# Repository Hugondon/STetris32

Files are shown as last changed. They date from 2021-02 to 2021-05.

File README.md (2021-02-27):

# STetris32
My version of the famous game "Tetris" using a system based on the Blue Pill dev board.
## Information
The sole purpose of this project is to recreate the game mechanics and introduce some other different features regarding in-game audio :). 
## Block Diagram
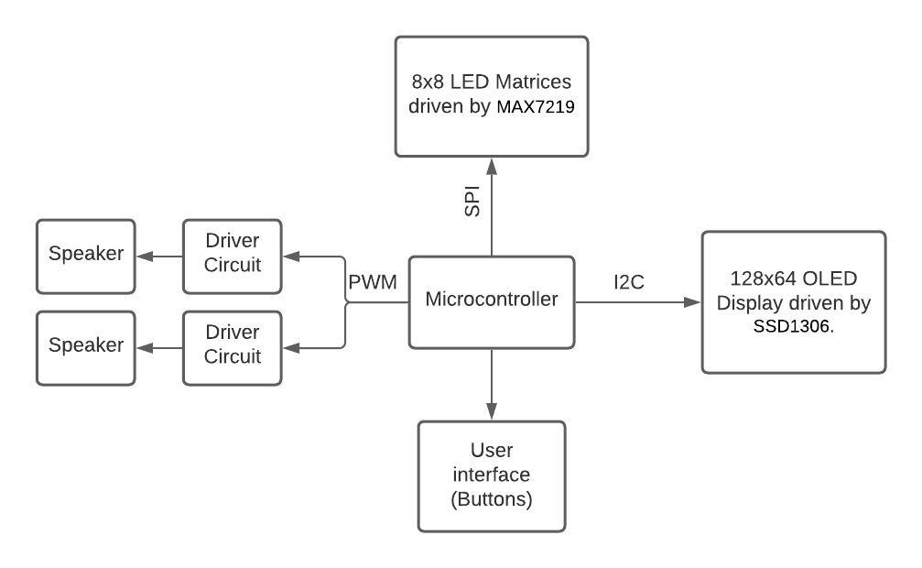
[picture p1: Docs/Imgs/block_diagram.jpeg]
block_diagram

The system can be summarized in three big modules:
1. Game Display Module.
    - SPI communication with MAX7219 to control two 8x8 LED matrices.
    - I2C communication with SSD1306 OLED Driver connected to 128x64 dot display to show the player's score and the current song being played.
2. Sound Module.
    - PWM + NPN BJT circuit driven 4 ohm speakers.
3. User Interface Module.
    - 6 buttons with different functionalities (up/down/left/right/center/reset).
## Schematic
The connections the user must make are the following:
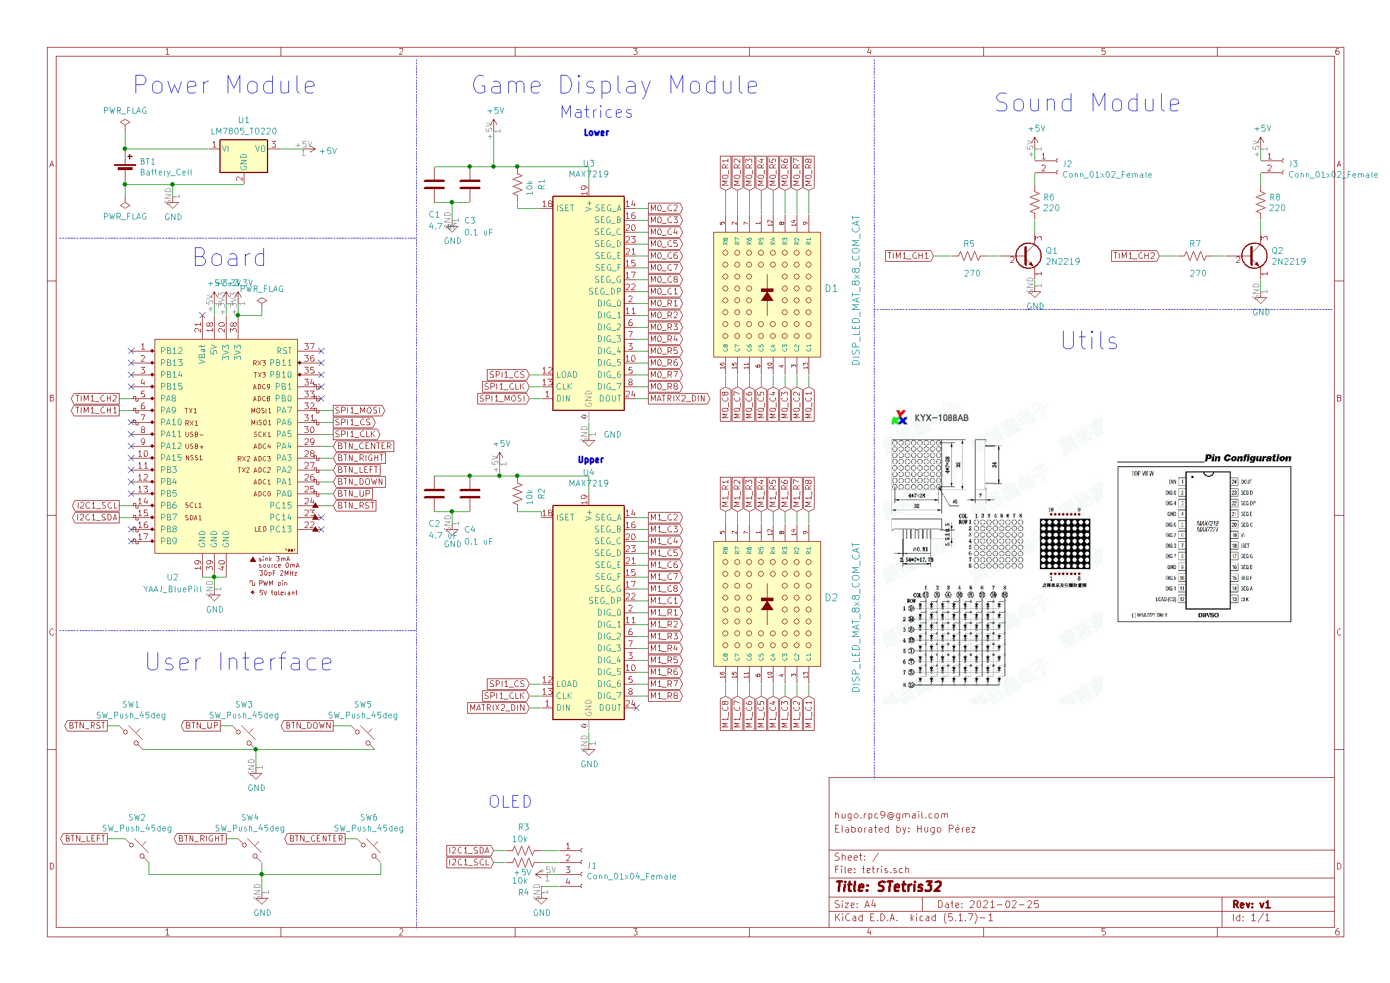
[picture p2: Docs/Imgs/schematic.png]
schematic

## Video

Pending upload.

## Useful Information
- [OLED Display](https://controllerstech.com/oled-display-using-i2c-stm32/)
- [Matrices](https://acoptex.com/project/160/basics-project-032a-8x8-dot-led-matrix-64-led-digital-display-common-anode-and-common-cathode-at-lex-c/)

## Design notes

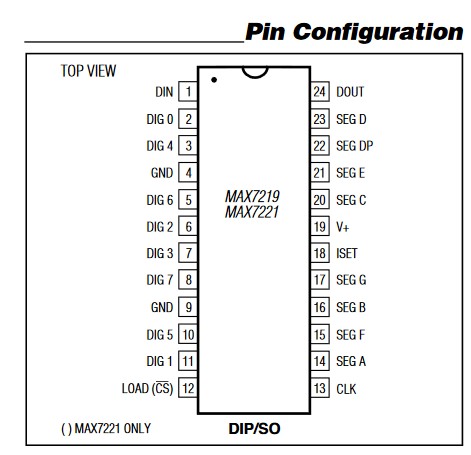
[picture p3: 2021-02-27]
Docs/Imgs/max7219_pinout.jpg

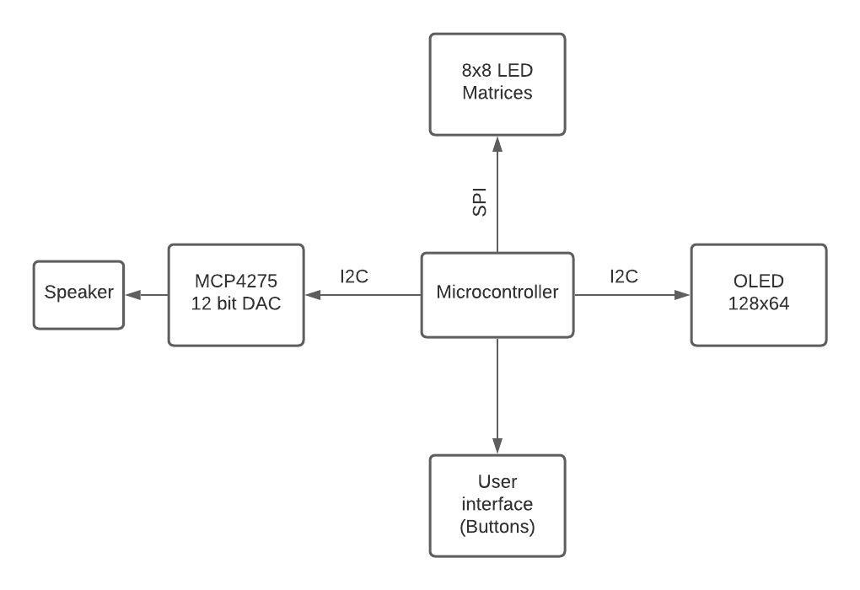
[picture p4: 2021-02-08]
Docs/Imgs/STetris32.jpeg

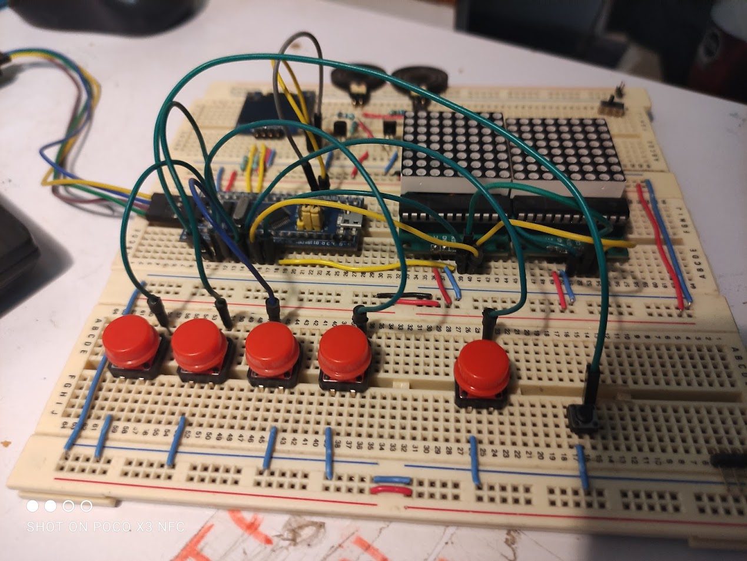
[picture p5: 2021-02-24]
Docs/Imgs/protoboard_project.jpg

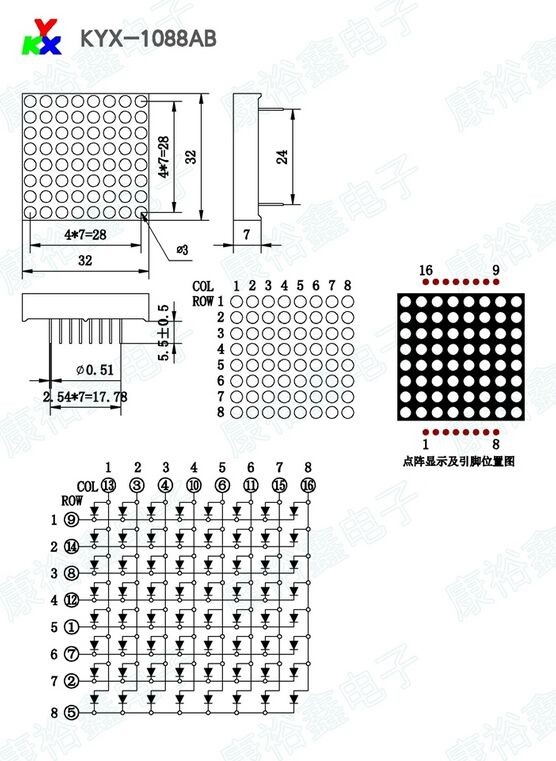
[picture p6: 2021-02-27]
Docs/Imgs/matrices_example.jpg

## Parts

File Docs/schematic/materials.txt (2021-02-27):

// Board
1. 1 x Bluepill					(2 x Conn_01x20_Female)	X

// User Interface
2. 6 x push-buttons				(SW_PUSH_12mm)		?

// Game Display Module
-- Matrices --
3. 2 x MAX7219					(DIP-24)		X
4. 4 x Conn_01x08_Female 			(matrices)		X
5. 2 x 10 uF Electrolytic Capacitor 		(4.7 uF 0603)		?
6. 2 x 0.1 uF Ceramic Capacitor			(0603)			X
7. 2 x 10K Resistance 				(0603)			X
-- OLED --
8. 2 x 10K Resistance				(0603)			X
9. 1 x Conn_01x04_Female						X

// Sound Module
9.  2 x BJT 2N2222A Transistors 		(TO - 92)		X
10. 2 x 330 Resistance (1/4 W)			(270 0603)		X
11. 2 x 68 Resistance (1/4 W)			(220 0603)		X
12. 2 x Conn_01x02_Female 			(Speakers)		X

// Power Module
12. 9V Battery					(BatteryHolder_MPD_BA9VPC_1xPP3)     ? 
13. 7805 regulator				(TO - 220)		X

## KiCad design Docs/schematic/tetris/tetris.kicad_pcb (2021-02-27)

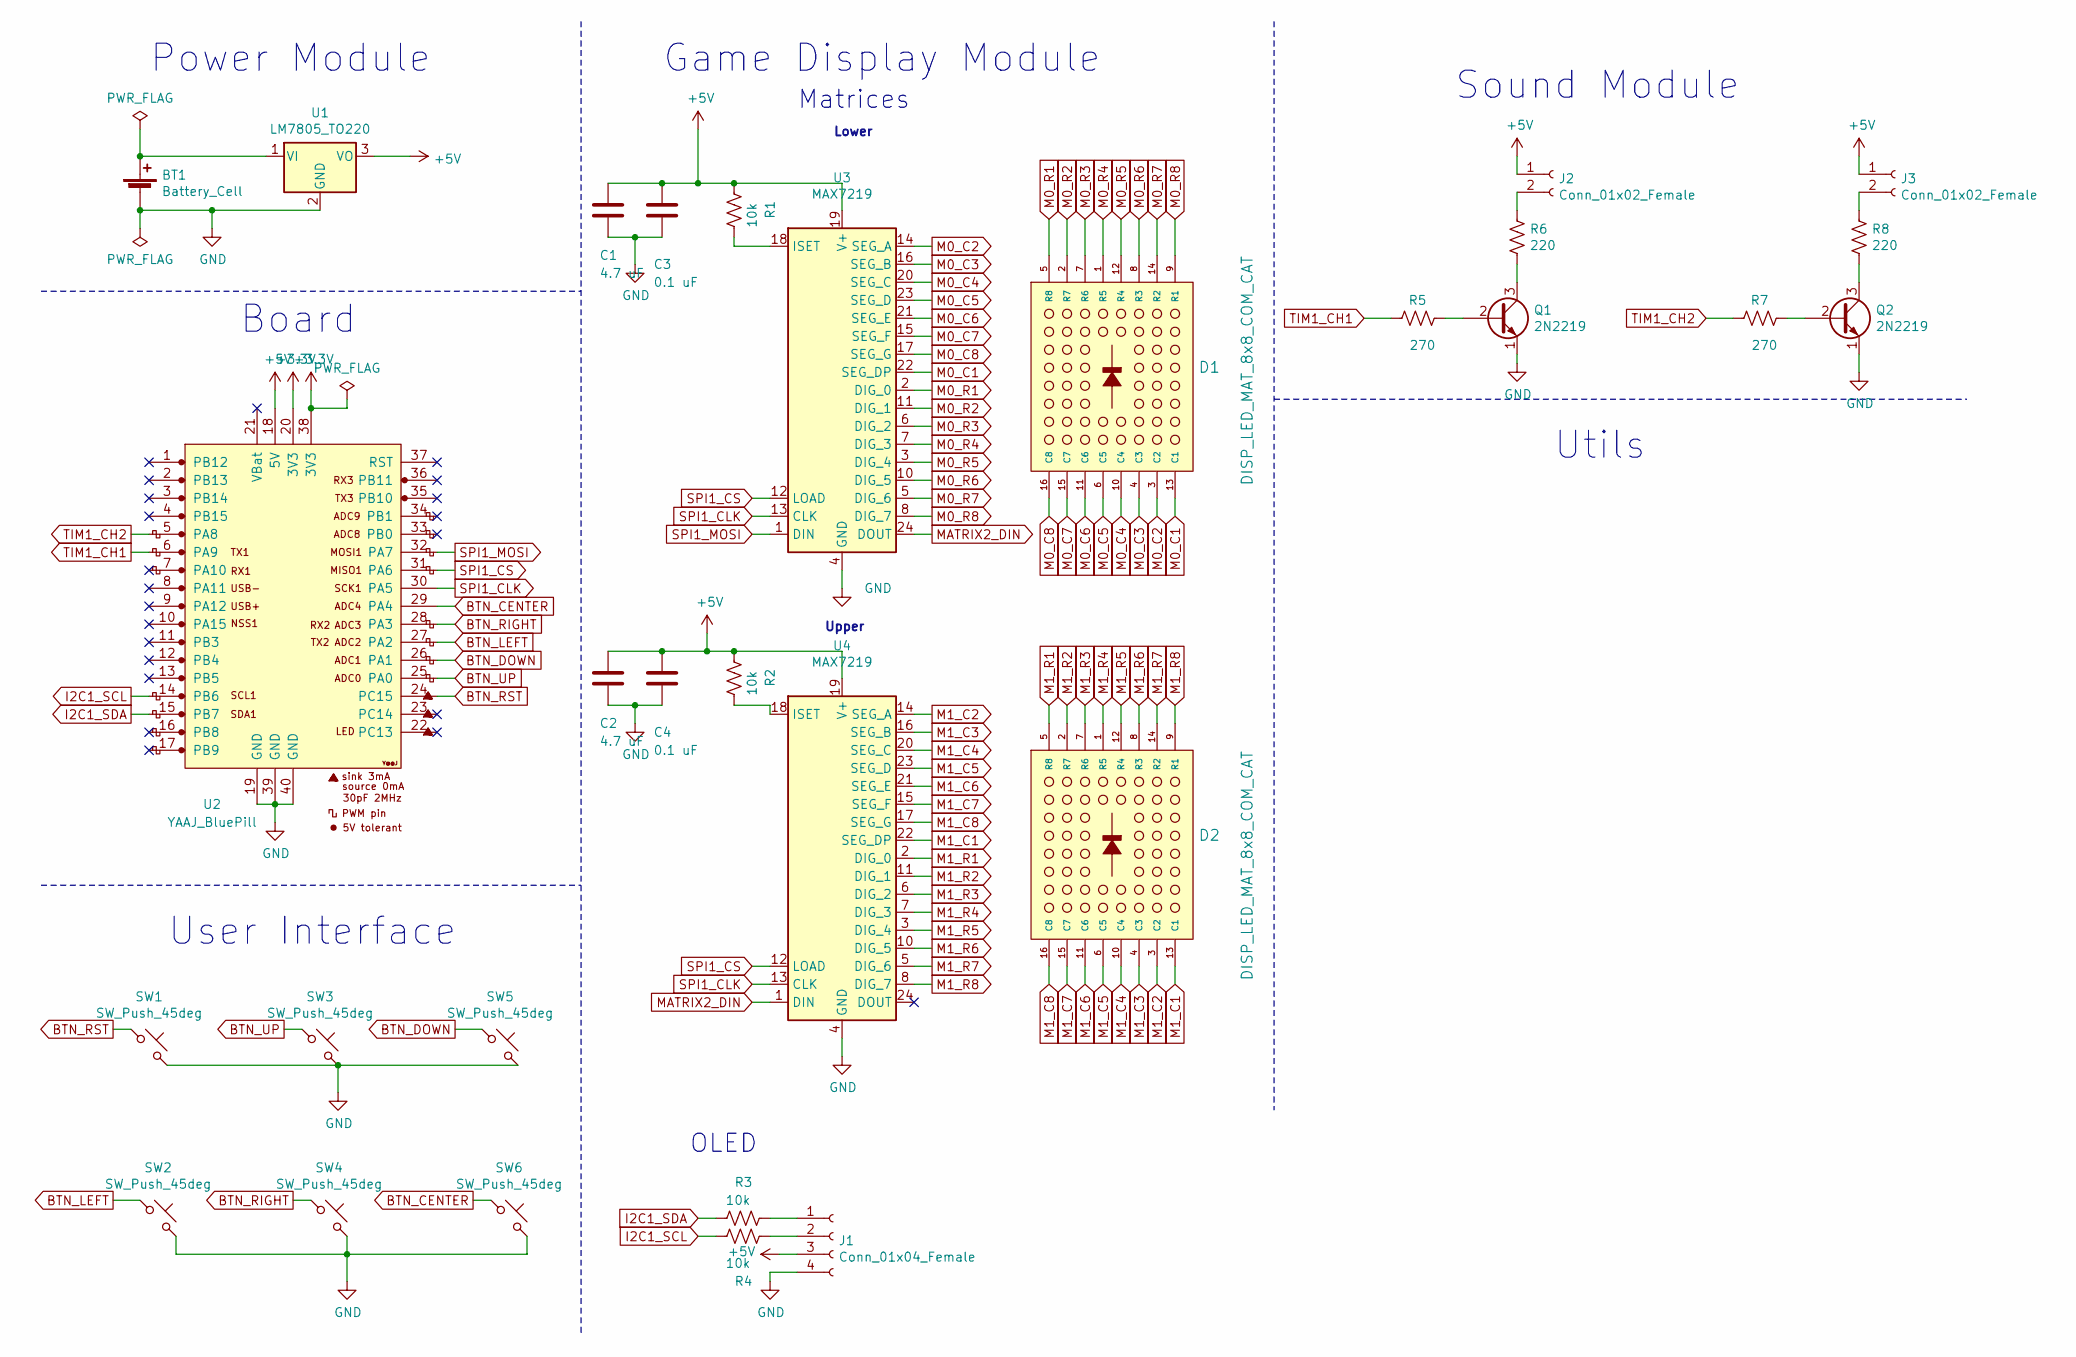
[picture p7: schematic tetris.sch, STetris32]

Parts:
BT1: Battery_Cell; BatteryHolder_MPD_BA9VPC_1xPP3
C1, C2: 4.7 uF; C_0603_1608Metric
C3, C4: 0.1 uF; C_0603_1608Metric
D1, D2: DISP_LED_MAT_8x8_COM_CAT; LED_8x8_3MM_32x32MM
J1: Conn_01x04_Female; PinHeader_1x04_P2.54mm_Vertical
J2, J3: Conn_01x02_Female; PinHeader_1x02_P2.54mm_Vertical
Q1, Q2: 2N2219; TO-92
R1, R2, R3, R4: 10k; R_0603_1608Metric
R5, R7: 270; R_0603_1608Metric
R6, R8: 220; R_0603_1608Metric
SW1, SW2, SW3, SW4, SW5, SW6: SW_Push_45deg; SW_PUSH-12mm
U1: LM7805_TO220; TO-220-3_Vertical
U2: YAAJ_BluePill; YAAJ_BluePill_1
U3, U4: MAX7219; DIP-24_W7.62mm

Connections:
+3V3: U2.20 (3V3), U2.38 (3V3)
+5V: C1.1, C2.1, C3.1, C4.1, J1.3, J2.1, J3.1, R1.1, R2.1, U1.3 (VO), U2.18 (5V), U3.19 (V+), U4.19 (V+)
BTN_CENTER: SW6.1, U2.29 (PA4)
BTN_DOWN: SW5.1, U2.26 (PA1)
BTN_LEFT: SW2.1, U2.27 (PA2)
BTN_RIGHT: SW4.1, U2.28 (PA3)
BTN_RST: SW1.1, U2.24 (PC15)
BTN_UP: SW3.1, U2.25 (PA0)
GND: BT1.2 (-), C1.2, C2.2, C3.2, C4.2, J1.4, Q1.1 (E), Q2.1 (E), SW1.2, SW2.2, SW3.2, SW4.2, SW5.2, SW6.2, U1.2 (GND), U2.19 (GND), U2.39 (GND), U2.40 (GND), U3.4 (GND), U3.9 (GND), U4.4 (GND), U4.9 (GND)
I2C1_SCL: R4.2, U2.14 (PB6)
I2C1_SDA: R3.2, U2.15 (PB7)
M0_C1: D1.13 (C1), U3.22 (SEG_DP)
M0_C2: D1.3 (C2), U3.14 (SEG_A)
M0_C3: D1.4 (C3), U3.16 (SEG_B)
M0_C4: D1.10 (C4), U3.20 (SEG_C)
M0_C5: D1.6 (C5), U3.23 (SEG_D)
M0_C6: D1.11 (C6), U3.21 (SEG_E)
M0_C7: D1.15 (C7), U3.15 (SEG_F)
M0_C8: D1.16 (C8), U3.17 (SEG_G)
M0_R1: D1.5 (R8), U3.2 (DIG_0)
M0_R2: D1.2 (R7), U3.11 (DIG_1)
M0_R3: D1.7 (R6), U3.6 (DIG_2)
M0_R4: D1.1 (R5), U3.7 (DIG_3)
M0_R5: D1.12 (R4), U3.3 (DIG_4)
M0_R6: D1.8 (R3), U3.10 (DIG_5)
M0_R7: D1.14 (R2), U3.5 (DIG_6)
M0_R8: D1.9 (R1), U3.8 (DIG_7)
M1_C1: D2.13 (C1), U4.22 (SEG_DP)
M1_C2: D2.3 (C2), U4.14 (SEG_A)
M1_C3: D2.4 (C3), U4.16 (SEG_B)
M1_C4: D2.10 (C4), U4.20 (SEG_C)
M1_C5: D2.6 (C5), U4.23 (SEG_D)
M1_C6: D2.11 (C6), U4.21 (SEG_E)
M1_C7: D2.15 (C7), U4.15 (SEG_F)
M1_C8: D2.16 (C8), U4.17 (SEG_G)
M1_R1: D2.5 (R8), U4.2 (DIG_0)
M1_R2: D2.2 (R7), U4.11 (DIG_1)
M1_R3: D2.7 (R6), U4.6 (DIG_2)
M1_R4: D2.1 (R5), U4.7 (DIG_3)
M1_R5: D2.12 (R4), U4.3 (DIG_4)
M1_R6: D2.8 (R3), U4.10 (DIG_5)
M1_R7: D2.14 (R2), U4.5 (DIG_6)
M1_R8: D2.9 (R1), U4.8 (DIG_7)
MATRIX2_DIN: U3.24 (DOUT), U4.1 (DIN)
unnamed: BT1.1 (+), U1.1 (VI)
unnamed: J1.1, R3.1
unnamed: J1.2, R4.1
unnamed: J2.2, R6.1
unnamed: J3.2, R8.1
unnamed: Q1.2 (B), R5.2
unnamed: Q1.3 (C), R6.2
unnamed: Q2.2 (B), R7.2
unnamed: Q2.3 (C), R8.2
unnamed: R1.2, U3.18 (ISET)
unnamed: R2.2, U4.18 (ISET)
SPI1_CLK: U2.30 (PA5), U3.13 (CLK), U4.13 (CLK)
SPI1_CS: U2.31 (PA6), U3.12 (LOAD), U4.12 (LOAD)
SPI1_MOSI: U2.32 (PA7), U3.1 (DIN)
TIM1_CH1: R5.1, U2.6 (PA9)
TIM1_CH2: R7.1, U2.5 (PA8)

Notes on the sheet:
Power Module
Board
User Interface
Game Display Module
Sound Module
Matrices
OLED
Utils
Lower
Upper

Board: 2 copper layers, 30 parts (0 on the bottom side), 60 nets, no tracks yet.

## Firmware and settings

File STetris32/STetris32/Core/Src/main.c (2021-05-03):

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
/* Includes ------------------------------------------------------------------*/
#include "main.h"

/* USER CODE BEGIN Includes */
#include <stdio.h>
#include <stdbool.h>
#include "ssd1306.h"
#include "fonts.h"
#include "test.h"
#include "sound.h"
#include "matrix.h"
/* USER CODE END Includes */

I2C_HandleTypeDef hi2c1;

SPI_HandleTypeDef hspi1;

TIM_HandleTypeDef htim1;
TIM_HandleTypeDef htim2;
TIM_HandleTypeDef htim3;

/* USER CODE BEGIN PV */

/*  Matrices Module */
extern row_t test_array[][8];
extern row_t figures_array[][8];
extern row_t matrix_buffer[8][8];

/*  Display Module */
uint32_t high_score = 9990;
char high_score_user[15];
char high_score_str[20];

/*  Audio Module */
extern uint16_t psc_array[];
extern uint16_t arr_array[];
extern uint8_t array_index;

extern const uint8_t melody[];
extern const size_t sizeof_melody;
extern uint8_t noteDurations[];

// General Purpose
bool center_flag = false;

/* USER CODE END PV */

void SystemClock_Config(void);
static void MX_GPIO_Init(void);
static void MX_SPI1_Init(void);
static void MX_I2C1_Init(void);
static void MX_TIM2_Init(void);
static void MX_TIM1_Init(void);
static void MX_TIM3_Init(void);
/* USER CODE BEGIN PFP */

// Interface
void update_player_score(int points);

/* USER CODE END PFP */

/**
  * @brief  The application entry point.
  * @retval int
  */
int main(void)
{
  /* MCU Configuration--------------------------------------------------------*/

  /* Reset of all peripherals, Initializes the Flash interface and the Systick. */
  HAL_Init();

  /* Configure the system clock */
  SystemClock_Config();

  /* Initialize all configured peripherals */
  MX_GPIO_Init();
  MX_SPI1_Init();
  MX_I2C1_Init();
  MX_TIM2_Init();
  MX_TIM1_Init();
  MX_TIM3_Init();
  /* USER CODE BEGIN 2 */

  // Matrices
  max_init();
  max_init();

  for(int i = 1 ; i < 9; i++){
	matrix_buffer[Upper][i-1] = figures_array[Upper][i-1];
	matrix_buffer[Lower][i-1] = figures_array[Lower][i-1];
	max_transfer_data(i, matrix_buffer[Upper][i-1], matrix_buffer[Lower][i-1]);
  }

  // LCD
  SSD1306_Init();
  SSD1306_Fill(0);

  SSD1306_GotoXY(25, 0);
  SSD1306_Puts("Welcome!", &Font_11x18, 1);
  SSD1306_GotoXY(30, 20);
  SSD1306_Puts("High Score", &Font_7x10, 1);

  SSD1306_GotoXY(0, 35);
  strcpy(high_score_user, "Hugo Perez");
  // snprintf(high_score_user, strlen("Hugo Perez") + 1, "Hugo Perez");
  sprintf(high_score_str, "%s - %05lu", high_score_user, high_score);
  SSD1306_Puts(high_score_str, &Font_7x10, 1);

  SSD1306_DrawLine(0, 32, 140, 32, 1);
  SSD1306_DrawLine(0, 45, 140, 45, 1);

  SSD1306_GotoXY(20, 50);
  SSD1306_Puts("Press Center", &Font_7x10, 1);

  SSD1306_UpdateScreen();

  int i = 0;
  /* USER CODE END 2 */

  /* Infinite loop */
  /* USER CODE BEGIN WHILE */
  while (1)
  {
    /* USER CODE END WHILE */

    /* USER CODE BEGIN 3 */
	  custom_tone(TIM_CHANNEL_1, melody[i], noteDurations[i]);
	  i = (i < sizeof_melody/sizeof(int) ? i + 1 : 0);
  }
  /* USER CODE END 3 */
}

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
/* USER CODE BEGIN 4 */
void max_transfer_command(uint8_t address, uint8_t data){
	HAL_GPIO_WritePin(SPI1_CS_GPIO_Port, SPI1_CS_Pin, GPIO_PIN_RESET);
	HAL_SPI_Transmit(&hspi1, &address, 1, 100);
	HAL_SPI_Transmit(&hspi1, &data, 1, 100);
	HAL_GPIO_WritePin(SPI1_CS_GPIO_Port, SPI1_CS_Pin, GPIO_PIN_SET);
}
void max_transfer_data(uint8_t address, uint8_t data, uint8_t data_2){
	HAL_GPIO_WritePin(SPI1_CS_GPIO_Port, SPI1_CS_Pin, GPIO_PIN_RESET);
	HAL_SPI_Transmit(&hspi1, &address, 1, 100);
	HAL_SPI_Transmit(&hspi1, &data, 1, 100);							// Upper
	HAL_SPI_Transmit(&hspi1, &address, 1, 100);
	HAL_SPI_Transmit(&hspi1, &data_2, 1, 100);							// Lower
	HAL_GPIO_WritePin(SPI1_CS_GPIO_Port, SPI1_CS_Pin, GPIO_PIN_SET);
}

void shift_matrix_content(uint8_t direction){
	row_t tmp_row;
	switch(direction){
	case up:
		  HAL_GPIO_TogglePin(LED_BUILTIN_GPIO_Port, LED_BUILTIN_Pin);
		  // Pending rotations
			for(int i = 1 ; i < 9; i++){
				matrix_buffer[Upper][i-1] = test_array[Upper][i-1];
				matrix_buffer[Lower][i-1] = test_array[Lower][i-1];
				max_transfer_data(i, matrix_buffer[Upper][i-1], matrix_buffer[Lower][i-1]);
			}
		break;
	case down:
		HAL_GPIO_TogglePin(LED_BUILTIN_GPIO_Port, LED_BUILTIN_Pin);

		tmp_row = matrix_buffer[Upper][0];

		for(int i = 1 ; i < 8; i++){
			matrix_buffer[Upper][i-1] = matrix_buffer[Upper][i];
			matrix_buffer[Lower][i-1] = matrix_buffer[Lower][i];
			max_transfer_data(i, matrix_buffer[Upper][i-1], matrix_buffer[Lower][i-1]);
		}
		matrix_buffer[Upper][7] = 0b00000000;
		matrix_buffer[Lower][7] = tmp_row;
		max_transfer_data(8, matrix_buffer[Upper][7], matrix_buffer[Lower][7]);
		break;
	case left:
		  HAL_GPIO_TogglePin(LED_BUILTIN_GPIO_Port, LED_BUILTIN_Pin);
		  for(int i = 1; i < 9; i++){
			matrix_buffer[Upper][i-1] = matrix_buffer[Upper][i-1] >> 1;
			matrix_buffer[Lower][i-1] = matrix_buffer[Lower][i-1] >> 1;
			max_transfer_data(i, matrix_buffer[Upper][i-1], matrix_buffer[Lower][i-1]);
		  }

		break;
	case right:
		  HAL_GPIO_TogglePin(LED_BUILTIN_GPIO_Port, LED_BUILTIN_Pin);
		  for(int i = 1; i < 9; i++){
			matrix_buffer[Upper][i-1] = matrix_buffer[Upper][i-1] << 1;
			matrix_buffer[Lower][i-1] = matrix_buffer[Lower][i-1] << 1;
			max_transfer_data(i, matrix_buffer[Upper][i-1], matrix_buffer[Lower][i-1]);
		  }
		break;
	}

}
void update_player_score(int points){
	high_score += points;
	SSD1306_GotoXY(0, 35);
	sprintf(high_score_str, "%s - %05lu", high_score_user, high_score);
	SSD1306_Puts(high_score_str, &Font_7x10, 1);
	SSD1306_UpdateScreen();
}

void custom_tone(uint32_t channel, uint8_t tone, uint8_t duration){
	  htim1.Init.Prescaler = psc_array[tone]-1;
	  htim1.Init.Period = arr_array[tone]-1;
	  HAL_TIM_Base_Init(&htim1);
	  HAL_TIM_PWM_Start(&htim1, TIM_CHANNEL_1);
	  HAL_TIM_PWM_Start(&htim1, TIM_CHANNEL_2);

	  htim3.Init.Prescaler = (1000*1.3)-1;
	  htim3.Init.Period = (1000/duration)-1;
	  HAL_Delay(200);
	  HAL_TIM_Base_Start_IT(&htim3);
}


void HAL_GPIO_EXTI_Callback(uint16_t GPIO_Pin){
	if(GPIO_Pin == BTN_UP_Pin) HAL_TIM_Base_Start_IT(&htim2);
	if(GPIO_Pin == BTN_DOWN_Pin) HAL_TIM_Base_Start_IT(&htim2);
	if(GPIO_Pin == BTN_LEFT_Pin) HAL_TIM_Base_Start_IT(&htim2);
	if(GPIO_Pin == BTN_RIGHT_Pin) HAL_TIM_Base_Start_IT(&htim2);
	if(GPIO_Pin == BTN_CENTER_Pin) HAL_TIM_Base_Start_IT(&htim2);
	if(GPIO_Pin == BTN_RST_Pin) HAL_TIM_Base_Start_IT(&htim2);


}
void HAL_TIM_PeriodElapsedCallback(TIM_HandleTypeDef *htim){
  /* Prevent unused argument(s) compilation warning */
  if(htim == &htim2){

	  if(!HAL_GPIO_ReadPin(BTN_UP_GPIO_Port, BTN_UP_Pin)){
		  update_player_score(1);
		  shift_matrix_content(up);
		  HAL_TIM_Base_Stop(&htim2);
	  }
	  if(!HAL_GPIO_ReadPin(BTN_DOWN_GPIO_Port, BTN_DOWN_Pin)){
		  update_player_score(-1);
		  shift_matrix_content(down);
		  HAL_TIM_Base_Stop(&htim2);
	  }
	  if(!HAL_GPIO_ReadPin(BTN_LEFT_GPIO_Port, BTN_LEFT_Pin)){
		  shift_matrix_content(left);
		  HAL_TIM_Base_Stop(&htim2);
	  }
	  if(!HAL_GPIO_ReadPin(BTN_RIGHT_GPIO_Port, BTN_RIGHT_Pin)){
		  shift_matrix_content(right);
		  HAL_TIM_Base_Stop(&htim2);
	  }
	  if(!HAL_GPIO_ReadPin(BTN_CENTER_GPIO_Port, BTN_CENTER_Pin)){
		  HAL_GPIO_TogglePin(LED_BUILTIN_GPIO_Port, LED_BUILTIN_Pin);
		  center_flag = true;

		  HAL_TIM_Base_Stop(&htim2);
	  }
	  if(!HAL_GPIO_ReadPin(BTN_RST_GPIO_Port, BTN_RST_Pin)){
		  HAL_GPIO_TogglePin(LED_BUILTIN_GPIO_Port, LED_BUILTIN_Pin);
		  HAL_TIM_Base_Stop(&htim2);
	  }

  }
  if(htim == &htim3){
	  	  HAL_TIM_Base_Stop(&htim3);
  }
}
/* USER CODE END 4 */
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


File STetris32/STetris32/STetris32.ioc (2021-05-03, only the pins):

Mcu.UserName=STM32F103C8Tx
PA0-WKUP.GPIO_Label=BTN_UP
PA0-WKUP.Signal=GPXTI0
PA1.GPIO_Label=BTN_DOWN
PA1.Signal=GPXTI1
PA13.Signal=SYS_JTMS-SWDIO
PA14.Signal=SYS_JTCK-SWCLK
PA2.GPIO_Label=BTN_LEFT
PA2.Signal=GPXTI2
PA3.GPIO_Label=BTN_RIGHT
PA3.Signal=GPXTI3
PA4.GPIO_Label=BTN_CENTER
PA4.Signal=GPXTI4
PA5.Signal=SPI1_SCK
PA6.GPIO_Label=SPI1_CS
PA6.Signal=GPIO_Output
PA7.Signal=SPI1_MOSI
PA8.Signal=S_TIM1_CH1
PA9.Signal=S_TIM1_CH2
PB6.Signal=I2C1_SCL
PB7.Signal=I2C1_SDA
PC13-TAMPER-RTC.GPIO_Label=LED_BUILTIN
PC13-TAMPER-RTC.Signal=GPIO_Output
PC15-OSC32_OUT.GPIO_Label=BTN_RST
PC15-OSC32_OUT.Signal=GPXTI15
PD0-OSC_IN.Signal=RCC_OSC_IN
PD1-OSC_OUT.Signal=RCC_OSC_OUT

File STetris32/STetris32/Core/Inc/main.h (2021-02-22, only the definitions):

#define LED_BUILTIN_Pin GPIO_PIN_13
#define LED_BUILTIN_GPIO_Port GPIOC
#define BTN_RST_Pin GPIO_PIN_15
#define BTN_RST_GPIO_Port GPIOC
#define BTN_RST_EXTI_IRQn EXTI15_10_IRQn
#define BTN_UP_Pin GPIO_PIN_0
#define BTN_UP_GPIO_Port GPIOA
#define BTN_UP_EXTI_IRQn EXTI0_IRQn
#define BTN_DOWN_Pin GPIO_PIN_1
#define BTN_DOWN_GPIO_Port GPIOA
#define BTN_DOWN_EXTI_IRQn EXTI1_IRQn
#define BTN_LEFT_Pin GPIO_PIN_2
#define BTN_LEFT_GPIO_Port GPIOA
#define BTN_LEFT_EXTI_IRQn EXTI2_IRQn
#define BTN_RIGHT_Pin GPIO_PIN_3
#define BTN_RIGHT_GPIO_Port GPIOA
#define BTN_RIGHT_EXTI_IRQn EXTI3_IRQn
#define BTN_CENTER_Pin GPIO_PIN_4
#define BTN_CENTER_GPIO_Port GPIOA
#define BTN_CENTER_EXTI_IRQn EXTI4_IRQn
#define SPI1_CS_Pin GPIO_PIN_6
#define SPI1_CS_GPIO_Port GPIOA

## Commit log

2021-02-11 added matrix functionality
    [matrix_forms_generator.xlsx]
2021-02-11 examples and buffers added
    [matrix_forms_generator.xlsx]
2021-02-12 added I2C display functionality
2021-02-12 added external interrupts + debouncing for buttons
2021-02-12 added stm32f103c8t6 datasheet
2021-02-13 added tests for pieces movement
    [matrix_forms_generator.xlsx]
2021-02-13 added movement through interrupts + shift func
2021-02-15 changed main menu
    [matrix_forms_generator.xlsx]
2021-02-22 added note durations and second PWM
2021-02-24 added image of protoboard circuit
2021-02-27 added schematic
    [tetris.kicad_pcb, tetris.sch]
2021-02-27 added schematic png
2021-02-27 LED matrix fix
    [tetris.kicad_pcb]
2021-03-07 akn-kicad-libs matrix fix
2021-03-31 el coco es mi novio

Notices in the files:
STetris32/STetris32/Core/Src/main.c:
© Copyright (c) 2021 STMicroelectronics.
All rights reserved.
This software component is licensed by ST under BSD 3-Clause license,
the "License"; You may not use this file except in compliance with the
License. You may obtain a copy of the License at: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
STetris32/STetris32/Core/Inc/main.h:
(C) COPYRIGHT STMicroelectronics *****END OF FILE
